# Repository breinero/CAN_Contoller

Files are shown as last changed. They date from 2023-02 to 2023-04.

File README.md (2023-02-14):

# Programable CAN Controller Node

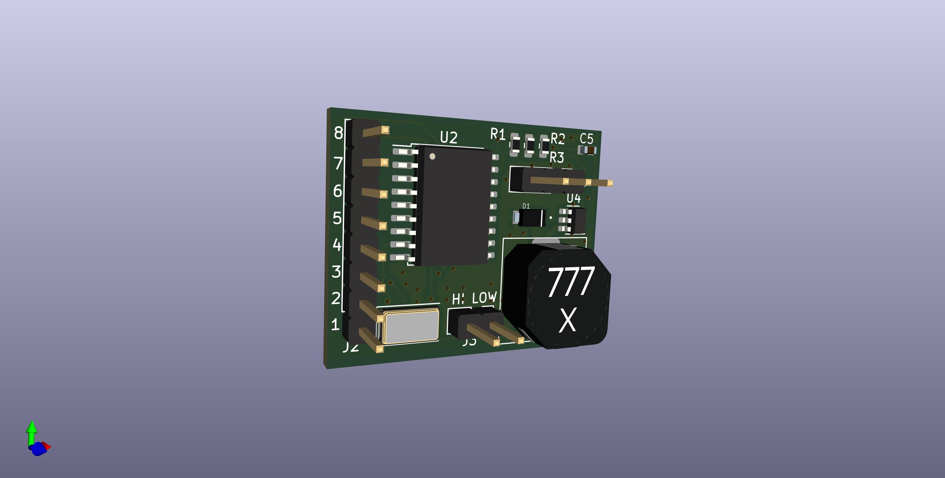
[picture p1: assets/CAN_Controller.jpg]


This design is a generic Controller Area Network (CAN) controller which can be programmed, and reprogramed for use in a given CAN compliant network. It is designed so that a user can create, or order many, duplicates of this board in batches, and then program each individual board with a specific function within a network. This board has also been designed to be as physically small as possible, so that this same board design can be used through out a given network. This project is purely a hardware design, and does not include an software or firmware to for communicating on a CAN network. 

This board is intended to be used in a variety of embedded use cases, but I inted to use this board for retrofitting a CAN network into vintage automobiles and in homebuilt and experimental aircraft. For that reaon the specific components of the design were selected for their quality and reliability.

## Features
1. Compliant with CAN Bus standards
1. The controller node is extensible, where the same unit can be configured and reconfigured to perform different functions
    1. Nodes of this design can collect sensor data, such as oil pressure, fuel level, or vehicle speed, and be able to control components such as turn signals and headlights.
1. Control at least 3 relays independently. E.G. headlights, high beams, turn signal. Or, control one servo 
1. Reprogrammable. The controller code can be updated with bug fixes and improvements
1. Can be added to an existing network with need to reprogram nodes on that network

## Non-Functional Requirements
1. Can be economically ordered via a PCB service
    1. Easy for myself, hobbyests, enthusiasts, or anyone else to acquire in batch sizes between 10 to 100 units
1. Minimal size, so that it can be used in tight spaces or within small component assemblies
1. Robust and reliable enough for automotive and experimental aircraft applications. 

## Non-Goals
1. Easily of assembly. Achieving the smallest footprint and volume takes priority over being able to hand solder this design. Folks have the option to over this part from a PCB assembly service or vendor, if they have difficulty assembling the board. 

# License 
The design files and documentation in this project are licensed under the [Creative Commons Attribution-ShareAlike 4.0 International license (CC BY-SA 4.0)](LICENSE)

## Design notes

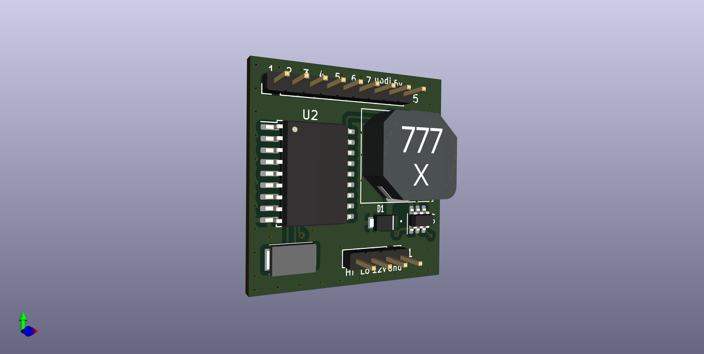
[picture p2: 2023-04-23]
assets/Homebrew_CAN_Node.png

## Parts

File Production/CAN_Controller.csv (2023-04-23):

Id | Designator | Footprint | Quantity | Designation | Supplier and ref
1 | J1 | PinHeader_1x04_P2.00mm_Vertical | 1 | Conn_01x04
2 | J5 | PinHeader_1x09_P2.00mm_Vertical | 1 | Conn_01x09
3 | U2 | SOIC-18W_7.5x11.6mm_P1.27mm | 1 | MCP2515-xSO
4 | Y1 | ECS80830QVSTR | 1 | 8 MHz
5 | L1 | Inductor_MSS1048-223 | 1 | 22 µH
6 | U4 | SOT-23-6 | 1 | MCP16331CH
7 | D1 | DFLS120LQ7 | 1 | DFLS120LQ-7
8 | C3,C4 | C3225_Commercial | 2 | 10uF
9 | C7,C6 | CAPC3216X180N | 2 | 10 uF
10 | R1,R2 | R_0603_1608Metric | 2 | 10
11 | U3 | SOIC-8_3.9x4.9mm_P1.27mm | 1 | MCP2551-I-SN
12 | R3 | R_0603_1608Metric | 1 | 52.3
13 | C2,C1 | C_0603_1608Metric | 2 | 22 pF
14 | C5 | CAPC1608X90N | 1 | 100 nF
15 | D2 | SOD3716X145N | 1 | 1N4148WQ-7-F
16 | U1 | SOIC-14_3.9x8.7mm_P1.27mm | 1 | ATtiny814-SS

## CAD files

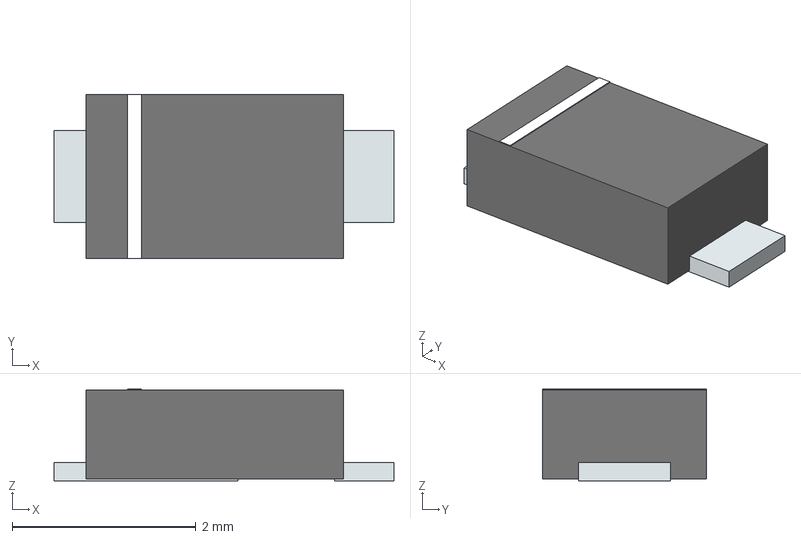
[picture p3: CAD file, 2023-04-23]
Hardware/step_files/DFLS120L-7.stp
3.70 x 1.78 x 1.00 mm
solidBody
solidLead
solidMark

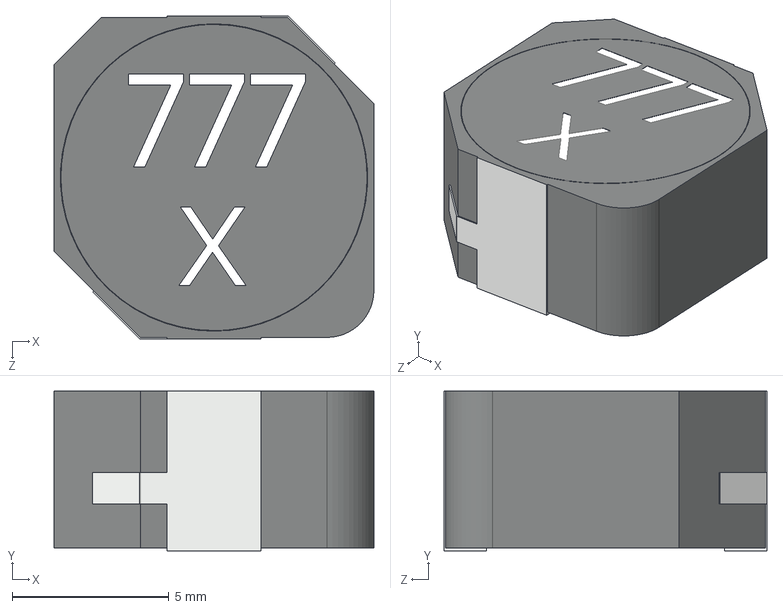
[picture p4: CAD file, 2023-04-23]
Hardware/step_files/Coilcraft-MSS1048.STEP
10.2 x 5.10 x 10.3 mm

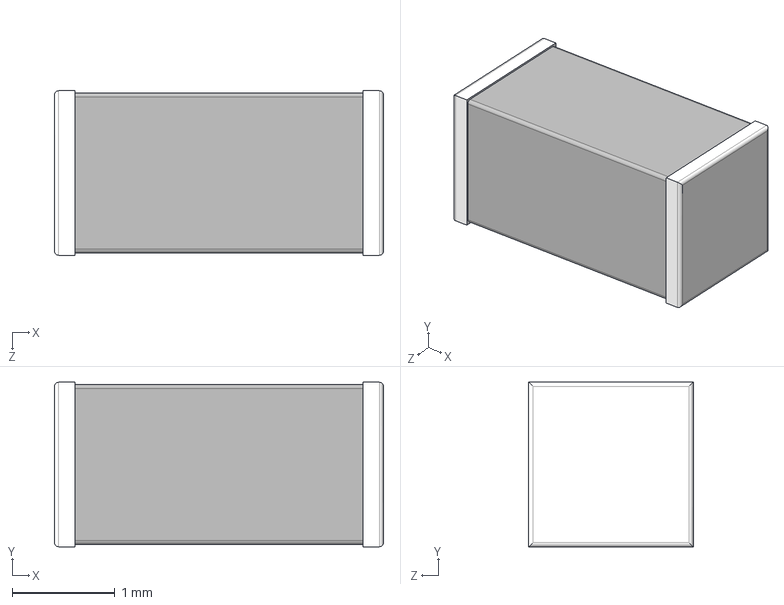
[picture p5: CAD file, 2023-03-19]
Hardware/step_files/C3216X7R1E106K160AB.stp
3.20 x 1.60 x 1.60 mm

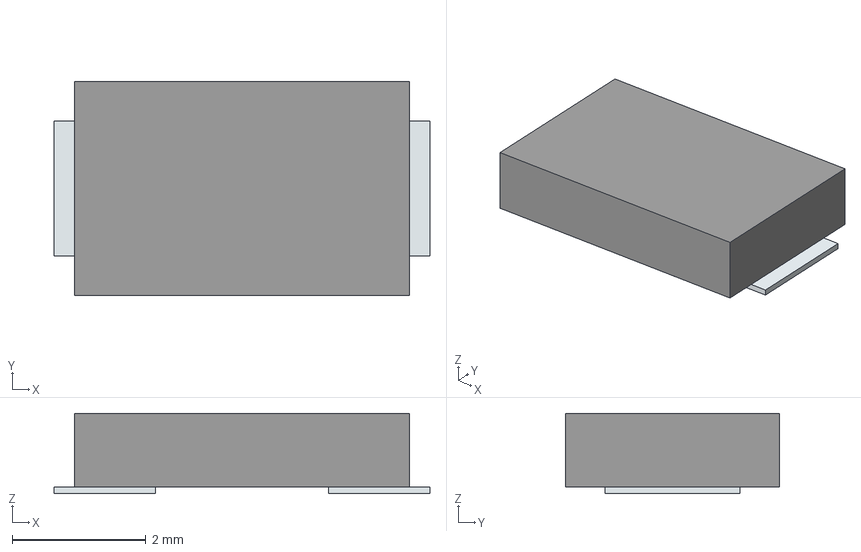
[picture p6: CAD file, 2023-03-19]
Hardware/step_files/ECS-80-8-30Q-VS-TR.stp
5.62 x 3.20 x 1.20 mm
Pins

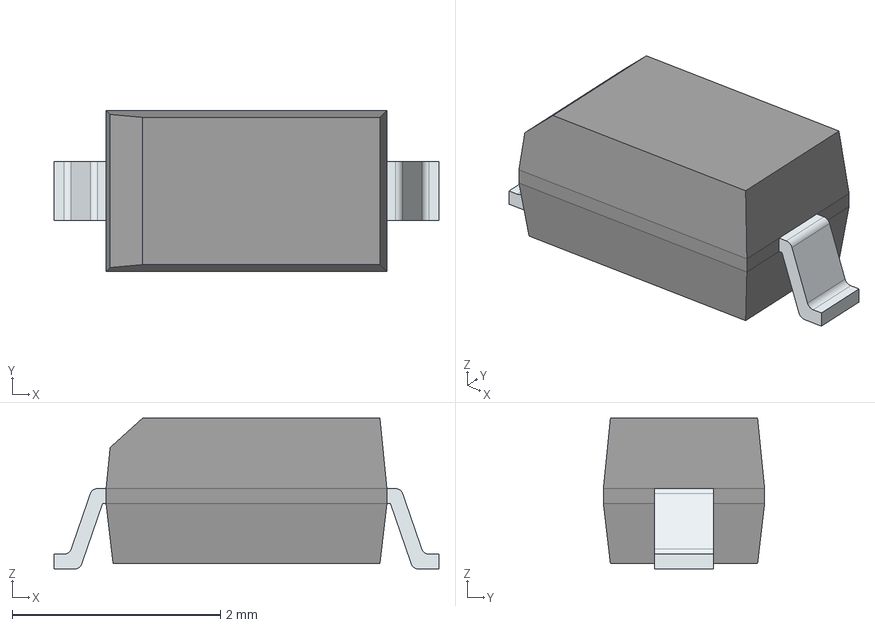
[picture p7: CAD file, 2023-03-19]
Hardware/step_files/1N4148WQ-7-F.stp
3.70 x 1.55 x 1.45 mm
FilletPinL
FilletPinR

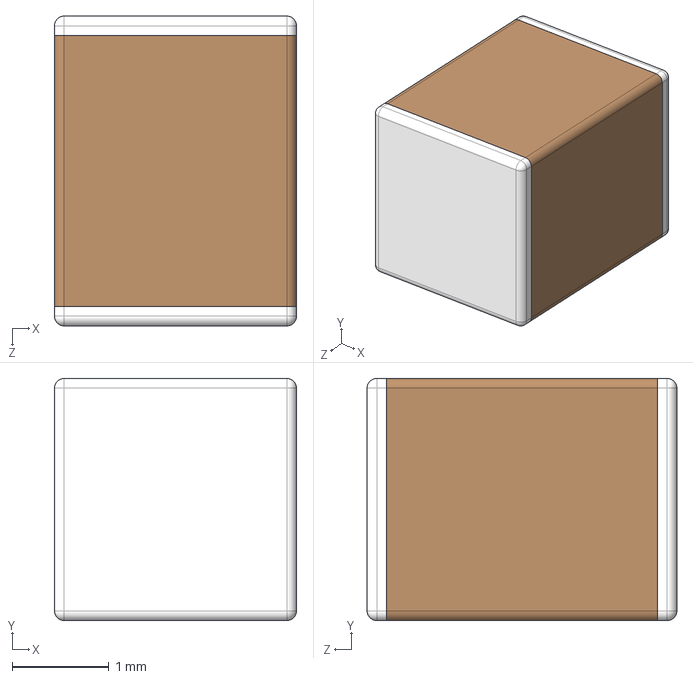
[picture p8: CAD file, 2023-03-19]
Hardware/step_files/C3225X7R1H106M250AC.stp
2.50 x 2.50 x 3.20 mm

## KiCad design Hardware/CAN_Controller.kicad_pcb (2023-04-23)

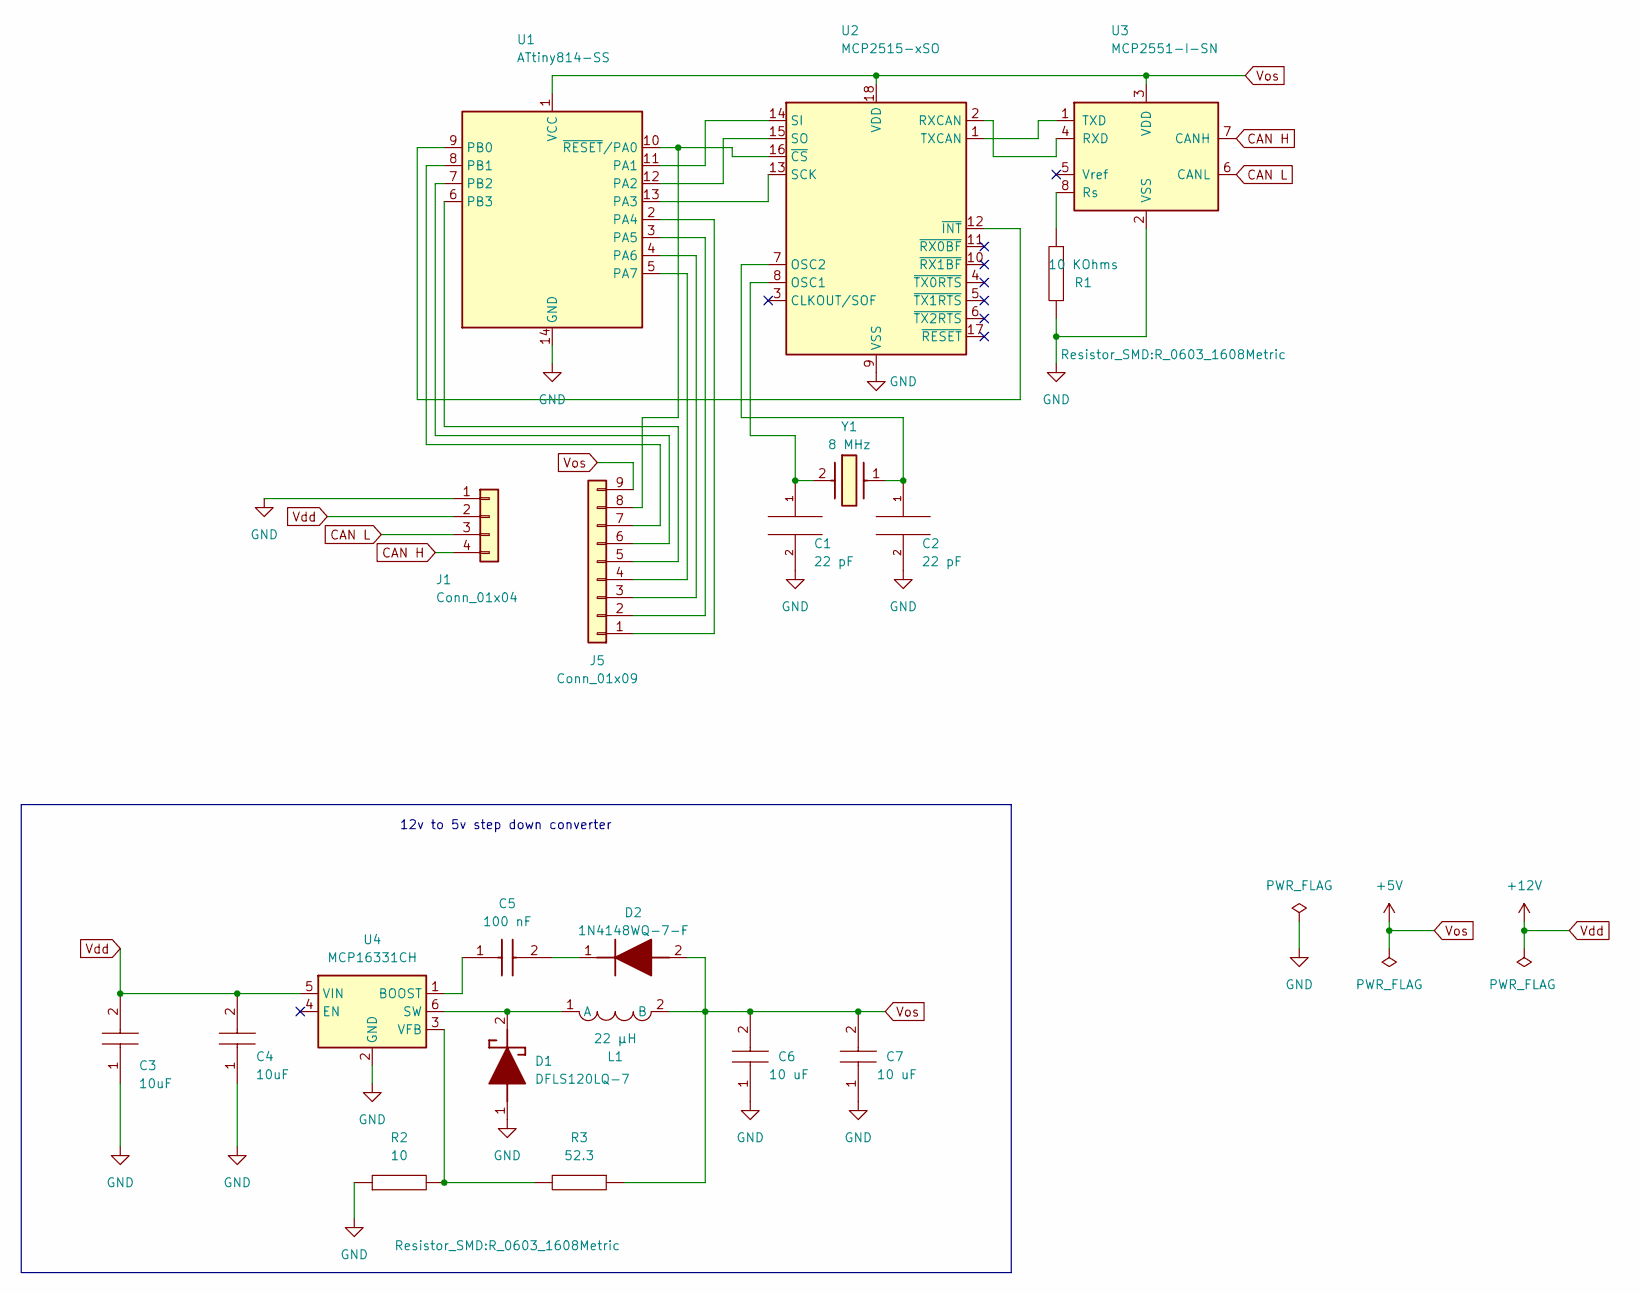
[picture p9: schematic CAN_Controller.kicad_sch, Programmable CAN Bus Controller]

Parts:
C1, C2: 22 pF; C_0603_1608Metric; Manufacturer_Part_Number C0603C220K3RACAUTO
C3, C4: 10uF; C3225_Commercial; Mouser Part Number 810-C3225X7R1H106MAC
C5: 100 nF; CAPC1608X90N; Mouser Part Number 581-060316C104K
C6, C7: 10 uF; CAPC3216X180N; Mouser Part Number 810-C3216X7R1E106K
D1: DFLS120LQ-7; DFLS120LQ7; Mouser Part Number 621-DFLS120LQ7
D2: 1N4148WQ-7-F; SOD3716X145N; Mouser Part Number 621-1N4148WQ-7-F
J1: Conn_01x04; PinHeader_1x04_P2.54mm_Vertical
J5: Conn_01x09; PinHeader_1x09_P2.54mm_Vertical
L1: 22 µH; Inductor_MSS1048-223
R1: 10 KOhms; R_0603_1608Metric
R2: 10; R_0603_1608Metric
R3: 52.3; R_0603_1608Metric
U1: ATtiny814-SS; SOIC-14_3.9x8.7mm_P1.27mm
U2: MCP2515-xSO; SOIC-18W_7.5x11.6mm_P1.27mm
U3: MCP2551-I-SN; SOIC-8_3.9x4.9mm_P1.27mm
U4: MCP16331CH; SOT-23-6
Y1: 8 MHz; ECS80830QVSTR; Mouser Part Number 520-80-8-30Q-VST

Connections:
CAN H: J1.4, U3.7 (CANH)
CAN L: J1.3, U3.6 (CANL)
GND: C1.2, C2.2, C3.1, C4.1, C6.1, C7.1, D1.1 (A), J1.1, R1.1, R2.1, U1.14 (GND), U2.9 (VSS), U3.2 (VSS), U4.2 (GND)
unnamed: D1.2 (K), L1.1 (A), U4.6 (SW)
unnamed: C5.2, D2.1 (K)
unnamed: J5.1, U1.2 (PA4)
unnamed: J5.2, U1.3 (PA5)
unnamed: J5.3, U1.4 (PA6)
unnamed: J5.4, U1.5 (PA7)
unnamed: J5.5, U1.6 (PB3)
unnamed: J5.6, U1.7 (PB2)
unnamed: J5.7, U1.8 (PB1)
unnamed: J5.8, U1.10 (~RESET/PA0), U2.16 (~CS)
unnamed: U1.11 (PA1), U2.14 (SI)
unnamed: U1.12 (PA2), U2.15 (SO)
unnamed: U1.13 (PA3), U2.13 (SCK)
unnamed: U1.9 (PB0), U2.12 (~INT)
unnamed: C1.1, U2.8 (OSC1), Y1.2 (OUT/IN)
unnamed: C2.1, U2.7 (OSC2), Y1.1 (IN/OUT)
unnamed: U2.2 (RXCAN), U3.4 (RXD)
unnamed: U2.1 (TXCAN), U3.1 (TXD)
unnamed: R1.2, U3.8 (Rs)
unnamed: C5.1, U4.1 (BOOST)
unnamed: R2.2, R3.2, U4.3 (VFB)
Vdd: C3.2, C4.2, J1.2, U4.5 (VIN)
Vos: C6.2, C7.2, D2.2 (A), J5.9, L1.2 (B), R3.1, U1.1 (VCC), U2.18 (VDD), U3.3 (VDD)

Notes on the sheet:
12v to 5v step down converter

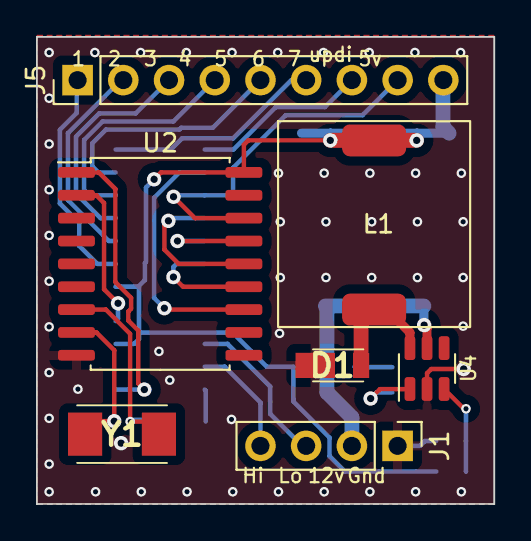
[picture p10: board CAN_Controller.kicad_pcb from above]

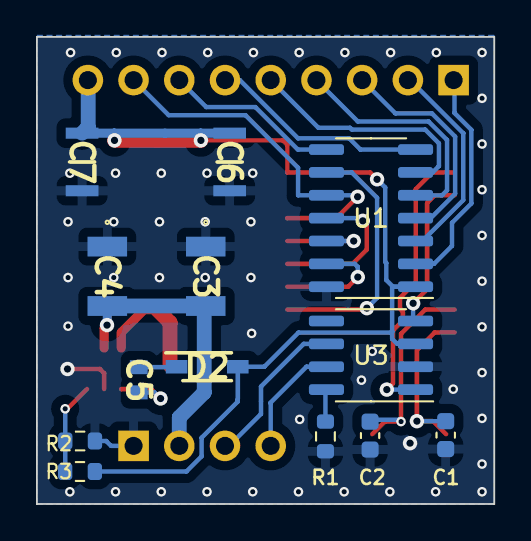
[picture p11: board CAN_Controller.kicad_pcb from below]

Board: 2 copper layers, 25.4 x 26.0 mm, 20 parts (13 on the bottom side), 26 nets.

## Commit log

2023-02-14 Added License, and double checked polarity of SMDs
    [CAN_Controller.kicad_sch]
2023-03-19 rearrainged components to reduce board size and added project footprints
    [1N4148WQ-7-F.stp, C3216X7R1E106K160AB.stp, C3225X7R1H106M250AC.stp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]
2023-03-19 removed gerber and drill file achive
2023-04-23 Reduced PCB footprint
    [CAN_Controller-B_Cu.gbr, CAN_Controller-B_Mask.gbr, CAN_Controller-B_Paste.gbr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]
